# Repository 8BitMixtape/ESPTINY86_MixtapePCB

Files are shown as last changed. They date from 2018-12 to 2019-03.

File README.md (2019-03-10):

# ESPTINY86_MixtapePCB

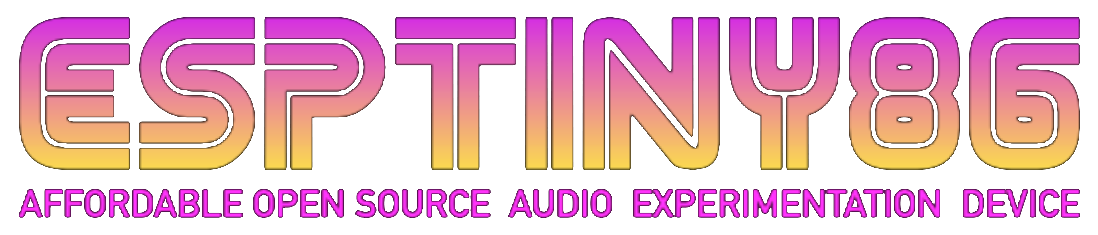
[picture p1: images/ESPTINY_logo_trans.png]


See more about the ESPTINY86 on https://github.com/esptiny86

# Where to get it

http://shop.8bitmixtape.cc/product/esptiny86-wifi-32bit-mixtape/

# Make Your Own 

## Preview of PCB gerber files

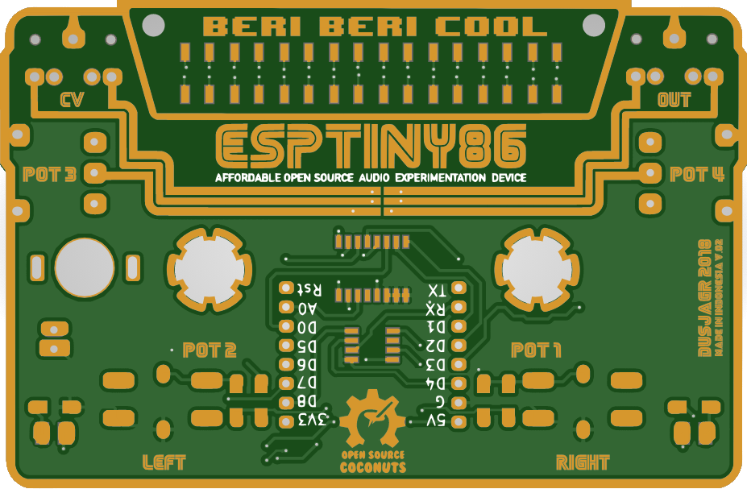
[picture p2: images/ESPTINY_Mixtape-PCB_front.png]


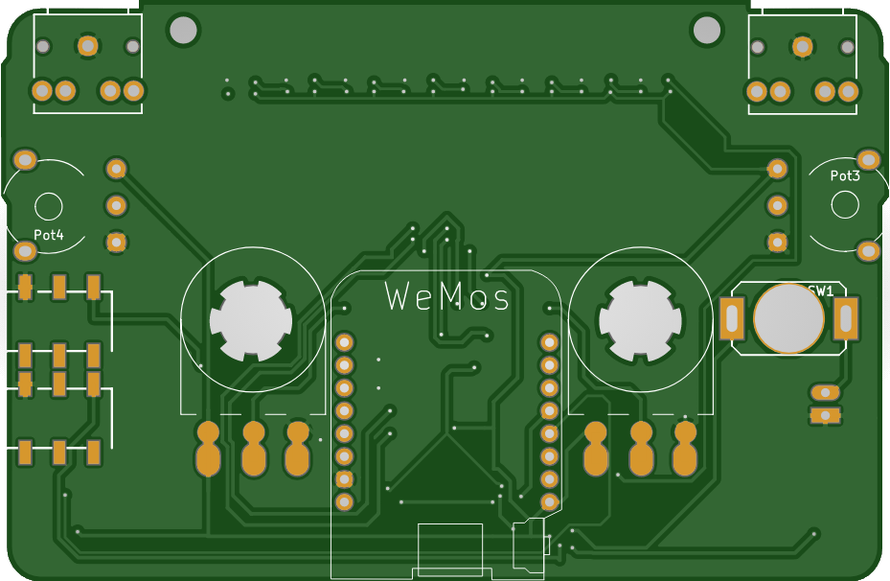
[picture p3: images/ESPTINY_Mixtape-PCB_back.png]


## How to solder it

Check the parts placement .pdf and warm up your soldering iron

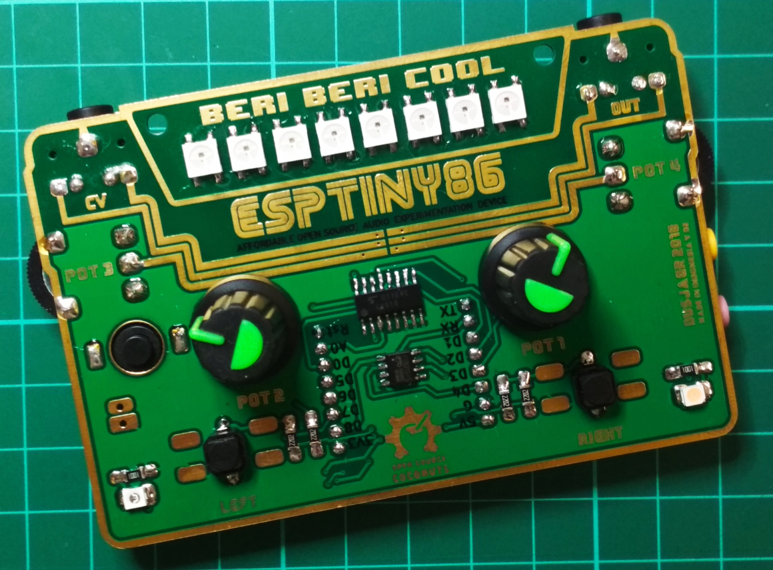
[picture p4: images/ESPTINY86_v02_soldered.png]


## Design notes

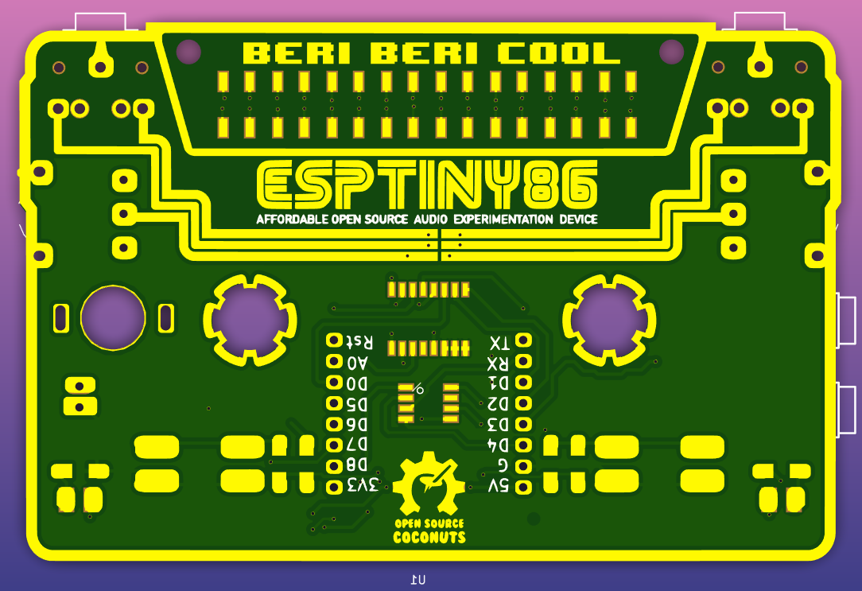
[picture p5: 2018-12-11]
images/ESPTINY86_3d_view_front_flat.png

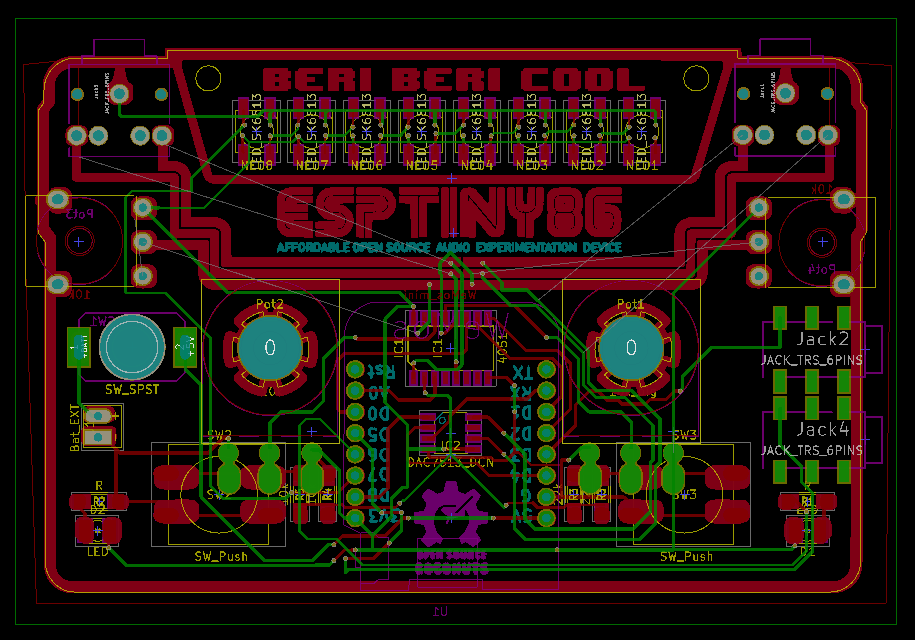
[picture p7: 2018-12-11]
images/ESPTINY86_KiCAD.png

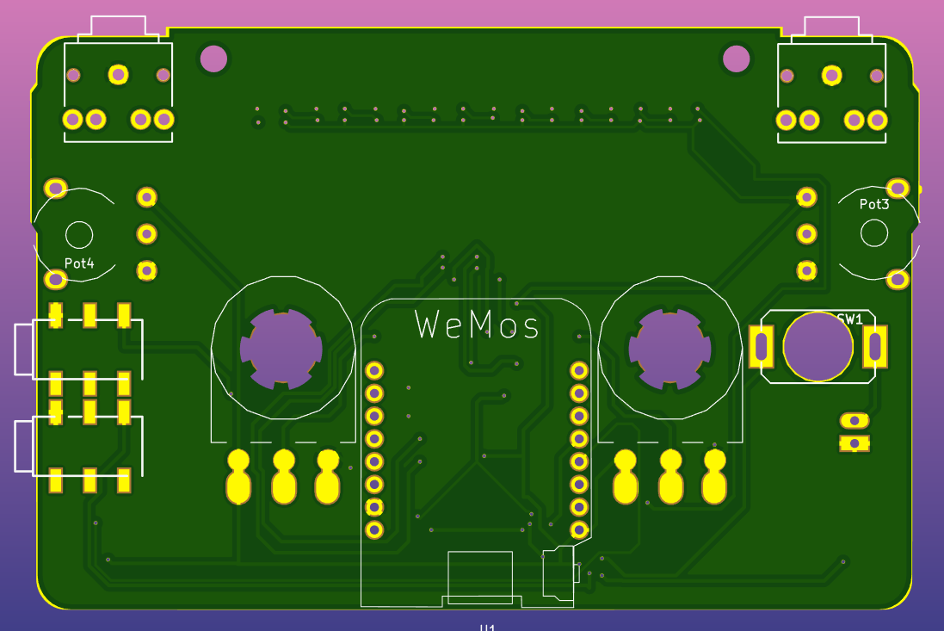
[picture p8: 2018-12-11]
images/ESPTINY86_3d_view_back_flat.png

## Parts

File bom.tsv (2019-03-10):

References | Qty | Description | Part Number | Manufacturer | Mouser | Digikey | Other Supplier
R1 | 1 | 22K 1206 | RC1206FR-0722KL | Yageo | 603-RC1206FR-0722KL | 311-22.0KFRCT-ND
R2 | 1 | 22K 1206 | RC1206FR-0722KL | Yageo | 603-RC1206FR-0722KL | 311-22.0KFRCT-ND
R3 | 1 | 22K 1206 | RC1206FR-0722KL | Yageo | 603-RC1206FR-0722KL | 311-22.0KFRCT-ND
R4 | 1 | 22K 1206 | RC1206FR-0722KL | Yageo | 603-RC1206FR-0722KL | 311-22.0KFRCT-ND
R5 | 1 | 1K 1206 | RC1206FR-071KL | Yageo | 603-RC1206FR-071KL | 311-1.00KFRCT-ND
R6 | 2 | 1K 1206 | RC1206FR-071KL | Yageo | 603-RC1206FR-071KL | 311-1.00KFRCT-ND
IC1 | 1 | CMOS 4051
IC2 | 1 | PT8211
D1 mini Pro | 1 | D1 mini Pro ESP8266 dev board
LED Power (red) | 1 | TOP-led (3528 package) | AA3528SURSK | Kingbright | 604-AA3528SURSK | 754-1537-1-ND
LED Signal (blue) | 1 | TOP-led (3528 package) | AA3528QBS/D | Kingbright | 604-AA3528QBS/D
Pot | 2 | 10k lin Potentiometer, 16mm (6mm shaft dia, 15mm shaft length) | P160KN-0QC15B10K | BI Technologies / TT Electronics | 858-P160KN-0QC15B10K
Pot-Wheel | 2 | 10k lin Wheel Potentiometer
Better to source on ali / taobao
NEO pixel | 1 | NEO pixel 10-pack (SK6812) | 1655 | Adafruit | 485-1655
Jack1 | 2 | Mini-Jack female 3.5mm | SJ1-3525NG | CUI | 490-SJ1-3525NG |  | https://www.aliexpress.com/item/1000pcs-Phone-Jack-3-5mm-5-pin-stereo-audio-socket-for-3-poles-earphone-plug-through/32664057697.html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
But1 | 2 | Tactile Switches | 1571621-1 | TE Connectivity / Alcoswitch | 506-1571621-1
SW1 | 1 | Push Switch |  |  |  |  | https://www.aliexpress.com/item/Free-shipping-200pcs-DC-30V-1A-Black-On-Off-Mini-Push-Button-Switch-for-Electric-Torch/32567227670.html
Jack3 | 2 | Mini-Jack female 3.5mm
Knob | 2 | from Taide |  |  |  |  | http://www.taydaelectronics.com/catalogsearch/result/?q=Black+Plastic+Knob+with

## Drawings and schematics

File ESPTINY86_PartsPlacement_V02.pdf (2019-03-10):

# Parts Placement - Complete

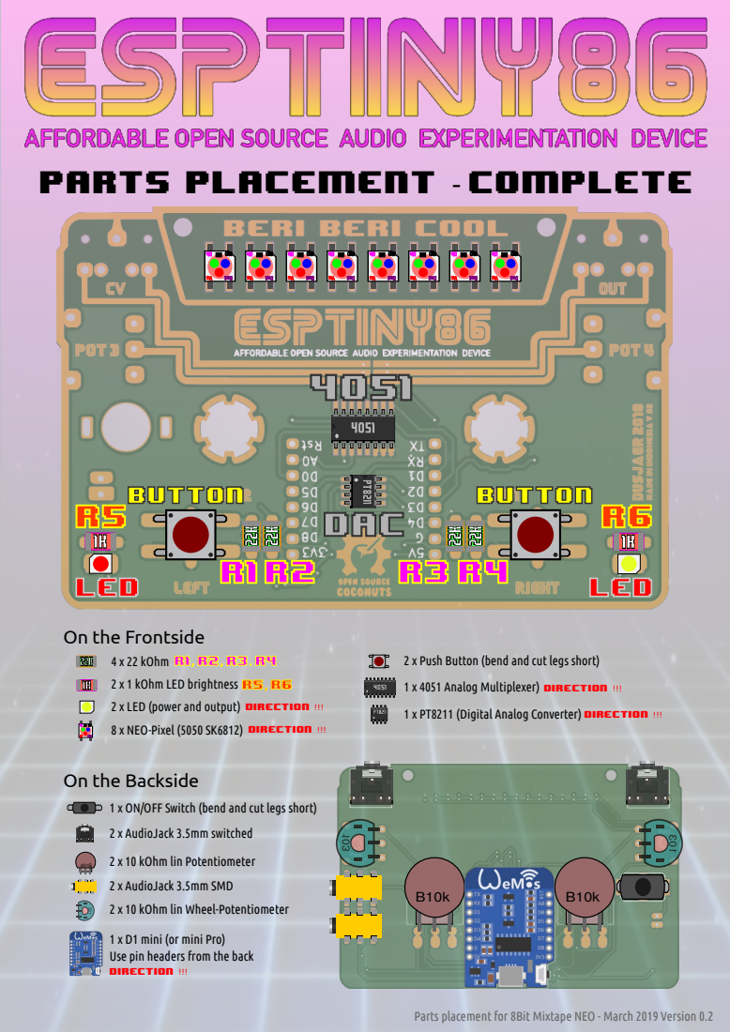
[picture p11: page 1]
LED; DAC; Button; direction !!!

On the Frontside

4 x 22 kOhm
2 x 1 kOhm LED brightness
2 x LED (power and output)
8 x NEO-Pixel (5050 SK6812)

2 x Push Button (bend and cut legs short)
1 x 4051 Analog Multiplexer)
1 x PT8211 (Digital Analog Converter)

On the Backside

1 x ON/OFF Switch (bend and cut legs short)
2 x AudioJack 3.5mm switched

2 x 10 kOhm lin Potentiometer
2 x AudioJack 3.5mm SMD
2 x 10 kOhm lin Wheel-Potentiometer

1 x D1 mini (or mini Pro)
Use pin headers from the back

Parts placement for 8Bit Mixtape NEO - March 2019 Version 0.2

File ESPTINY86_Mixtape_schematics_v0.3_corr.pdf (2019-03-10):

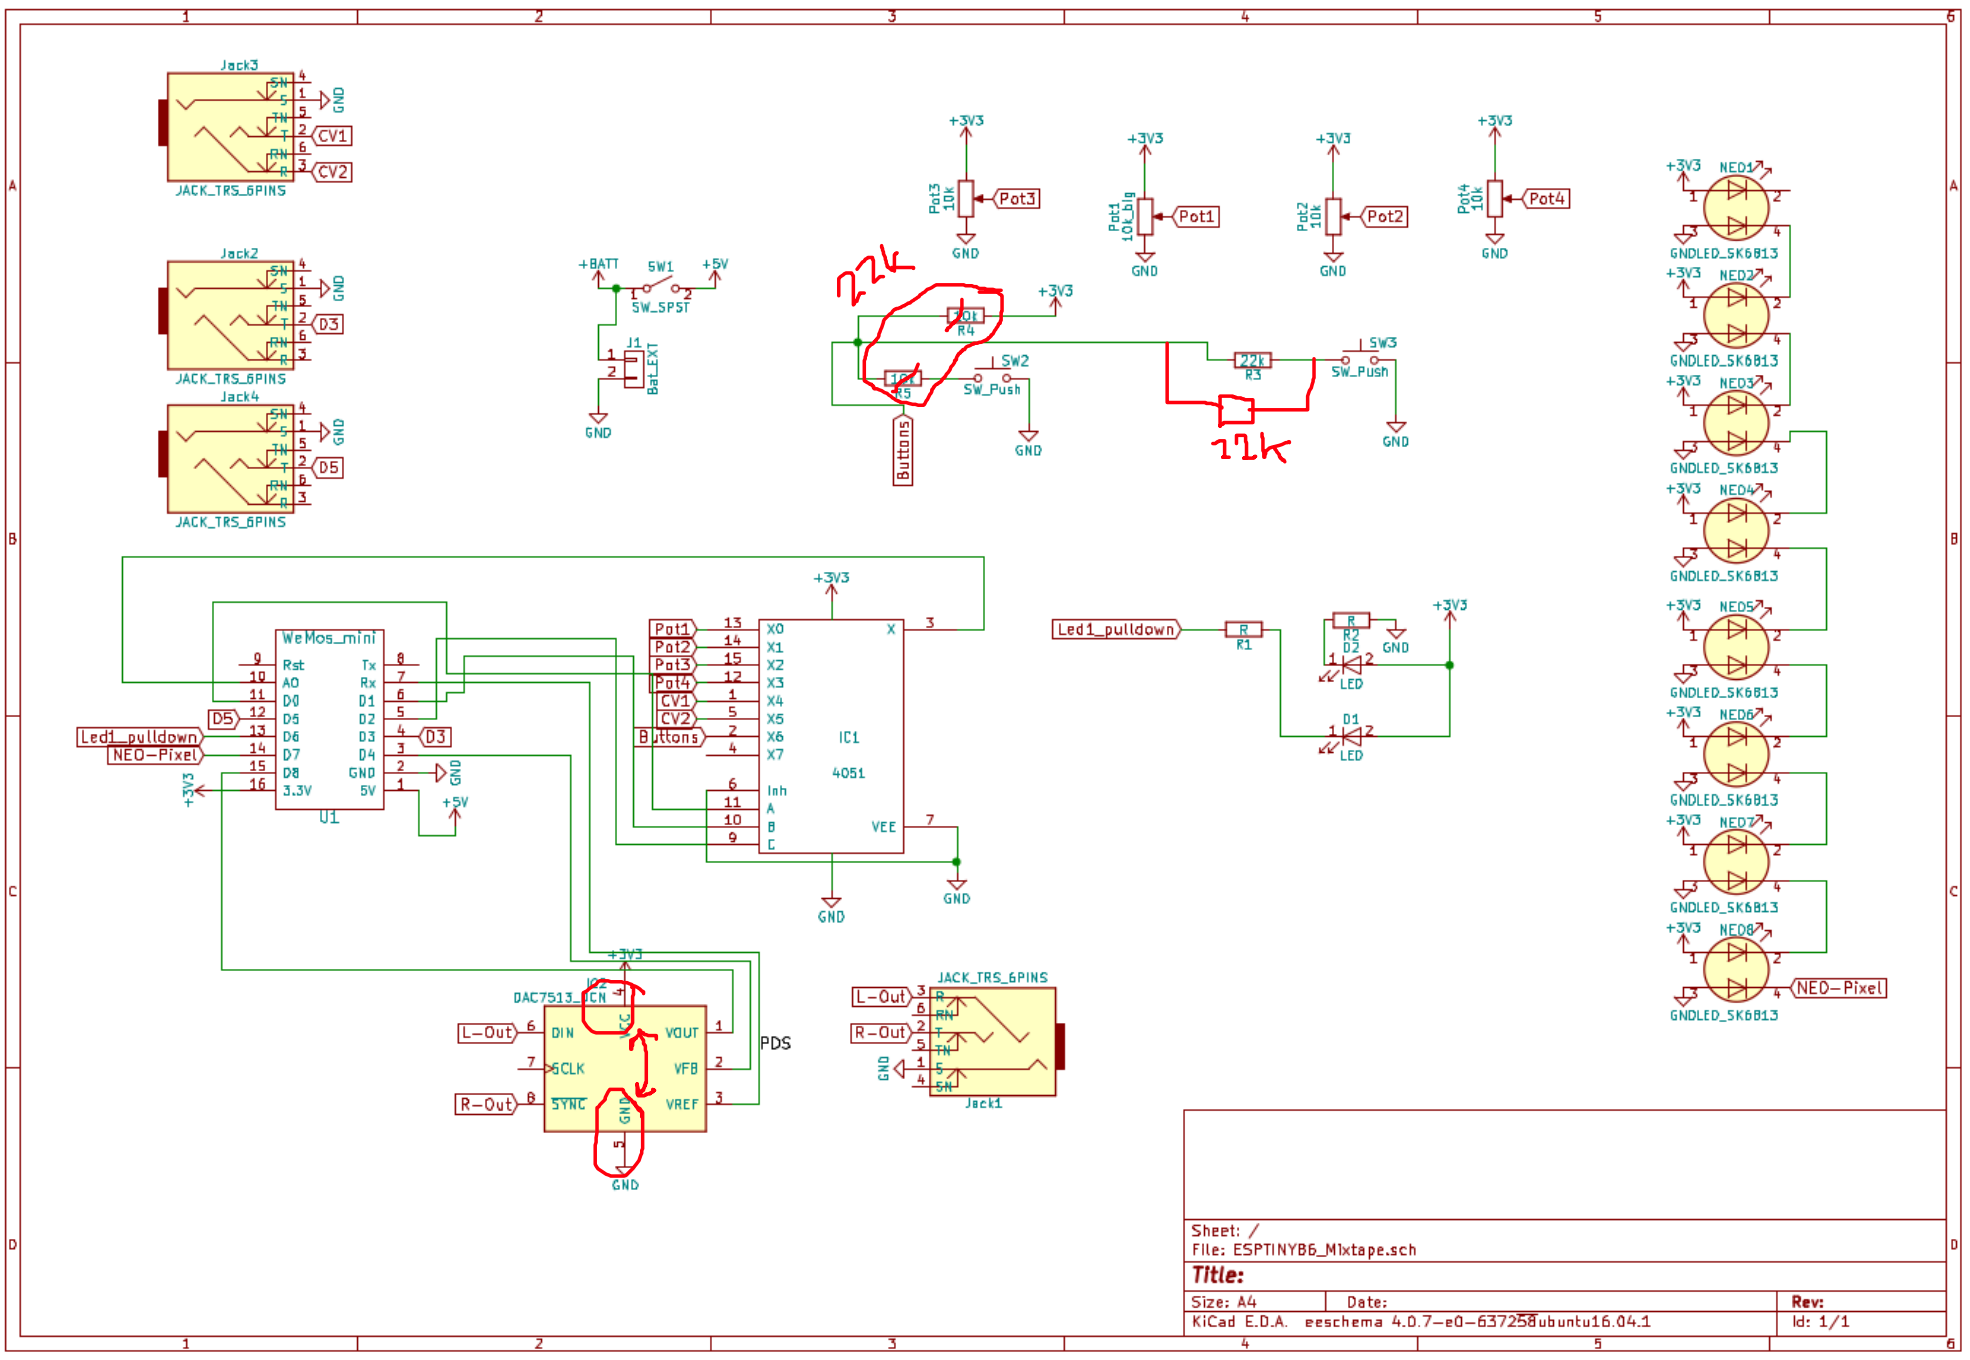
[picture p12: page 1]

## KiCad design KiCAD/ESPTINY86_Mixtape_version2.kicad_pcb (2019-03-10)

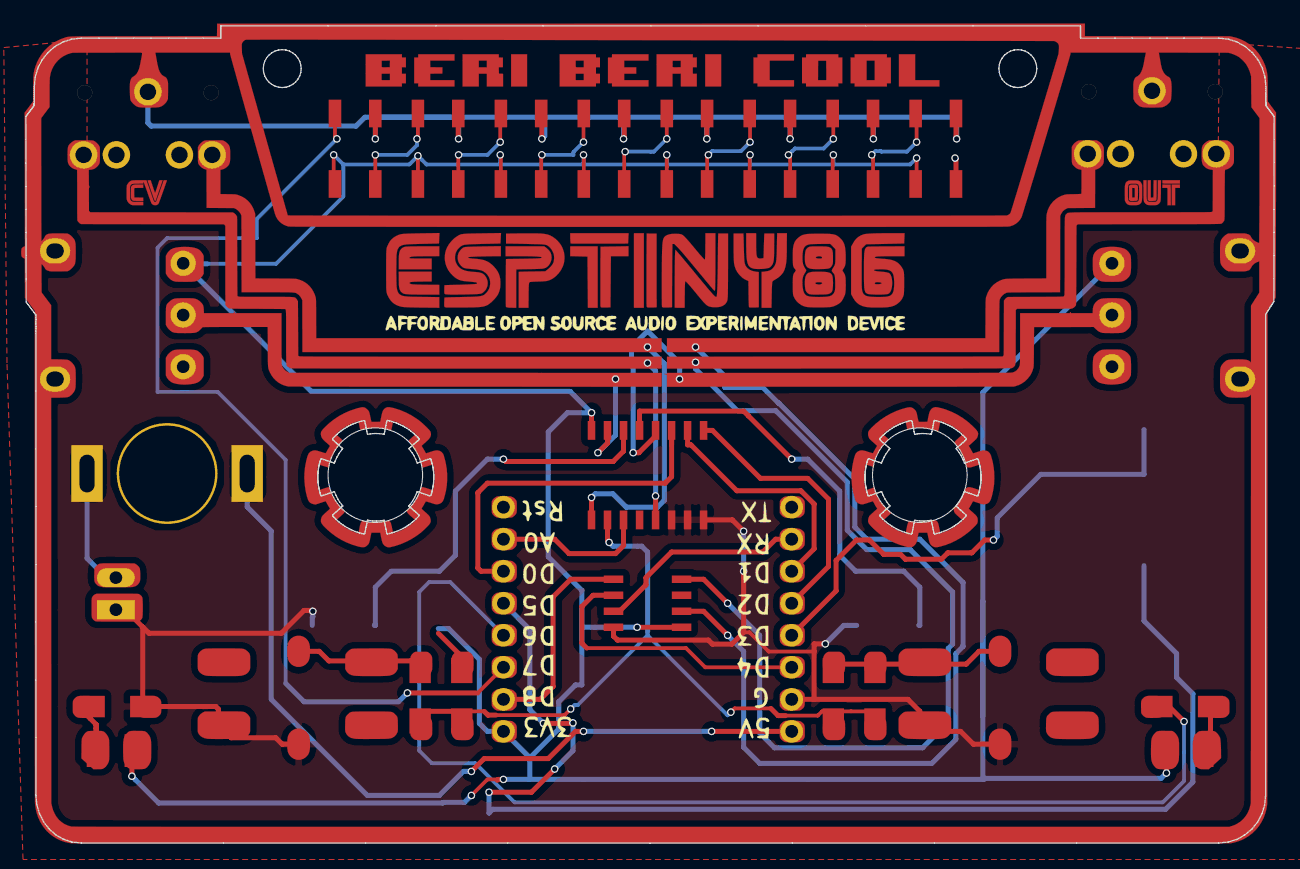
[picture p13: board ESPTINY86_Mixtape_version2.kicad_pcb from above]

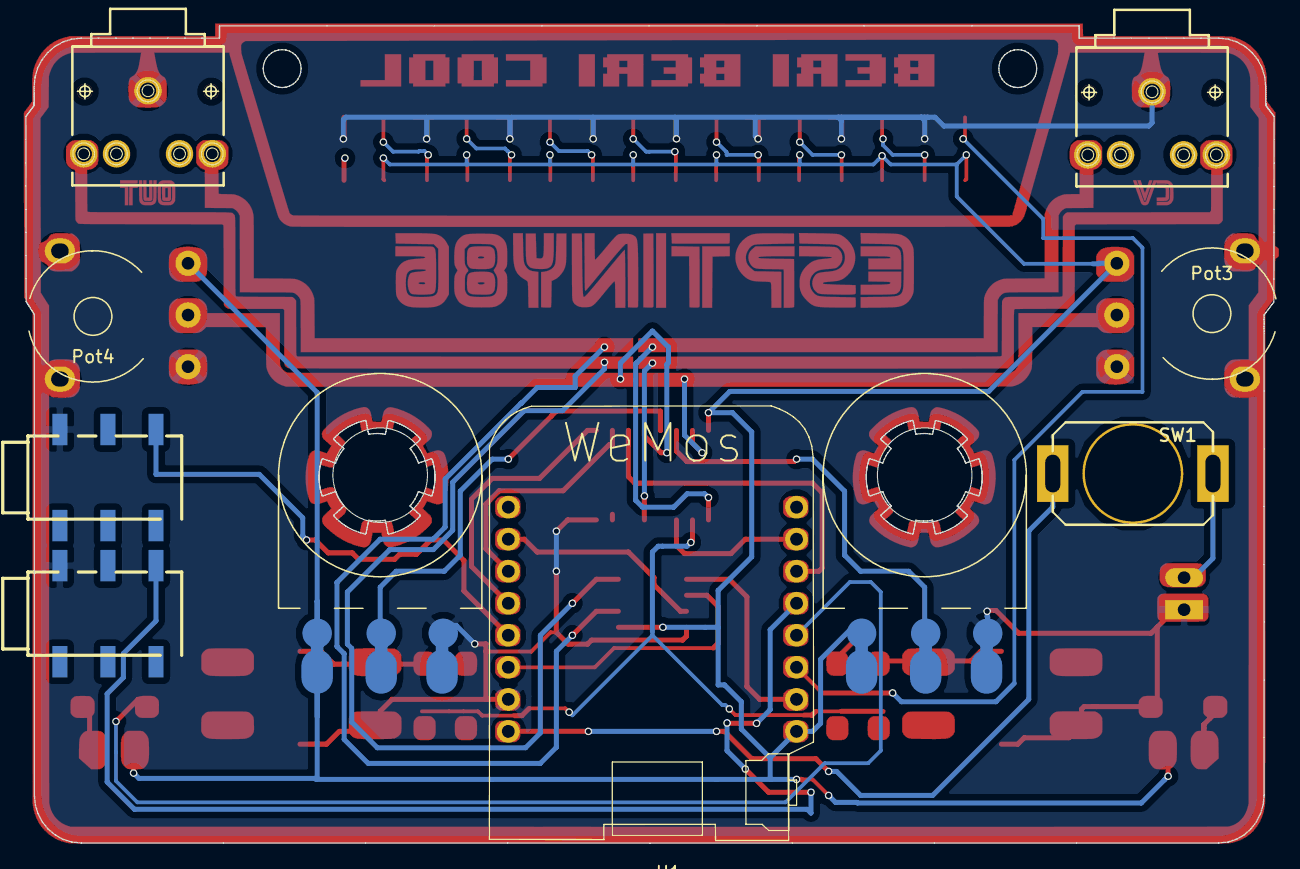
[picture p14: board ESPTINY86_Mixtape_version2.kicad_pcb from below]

Board: 2 copper layers, 99.0 x 64.8 mm, 32 parts (8 on the bottom side), 35 nets.

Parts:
Coconut: LOGO; Coconut_Logo_small_Mask
D1, D2: LED; TopLED_2835
IC1: 4051; 4xxx_SOIC-16W_Pitch1.27mm
IC2: DAC7513_DCN; SOIC-8_3.9x4.9mm_Pitch1.27mm
J1: Bat_EXT; Bat_connector+-
Jack1, Jack3: JACK_TRS_6PINS; AUDIO-Jack_3.5mm_5Pin
Jack2, Jack4: JACK_TRS_6PINS; AUDIO-JACK-3.5mm_SMD_noHole
NEO1, NEO2, NEO3, NEO4, NEO5, NEO6, NEO7, NEO8: LED_SK6813; Mixtape_NEO_WS2812B
Pot1: 10k_big; Potentiometer_backPads_noHole
Pot2: 10k; Potentiometer_backPads_noHole
Pot3: 10k; Potentiometer_wheel_inv
Pot4: 10k; Potentiometer_wheel
R1, R2: R; R_1206_Mixtape
R3, R3#2: 22k; R_1206_Mixtape
R4, R5: 10k; R_1206_Mixtape
SW1: SW_SPST; Push_SWITCH_hole
SW2, SW3: SW_Push; SW_PUSH-8mm_SMD
U1: WeMos_mini; WeMOS_ESP

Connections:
+3V3: D1.2, D2.2, IC1.16, IC2.5, NEO1.1, NEO2.1, NEO3.1, NEO4.1, NEO5.1, NEO6.1, NEO7.1, NEO8.1, Pot1.1, Pot2.1, Pot3.1, Pot4.1, R4.1, U1.16
+5V: SW1.2, U1.1
+BATT: J1.1, SW1.1
Buttons: IC1.2, R3.2, R3#2.2, R4.2, R5.2
CV1: IC1.1, Jack3.2
CV2: IC1.5, Jack3.3
D3: Jack2.2, U1.4
D5: Jack4.2, U1.12
GND: IC1.6, IC1.7, IC1.8, IC2.4, J1.2, Jack1.1, Jack2.1, Jack3.1, Jack4.1, NEO1.3, NEO2.3, NEO3.3, NEO4.3, NEO5.3, NEO6.3, NEO7.3, NEO8.3, Pot1.3, Pot2.3, Pot3.3, Pot4.3, R2.1, SW2.2, SW3.2, U1.2
L-Out: IC2.6, Jack1.3
Led1_pulldown: R1.2, U1.13
NEO-Pixel: NEO8.4, U1.14
unnamed: D1.1, R1.1
unnamed: D2.1, R2.2
unnamed: IC1.3, U1.10
unnamed: IC1.9, U1.5
unnamed: IC1.10, U1.6
unnamed: IC1.11, U1.11
unnamed: IC2.1, U1.15
unnamed: IC2.3, U1.7
unnamed: NEO1.4, NEO2.2
unnamed: NEO2.4, NEO3.2
unnamed: NEO3.4, NEO4.2
unnamed: NEO4.4, NEO5.2
unnamed: NEO5.4, NEO6.2
unnamed: NEO6.4, NEO7.2
unnamed: NEO7.4, NEO8.2
unnamed: R3.1, R3#2.1, SW3.1
unnamed: R5.1, SW2.1
Pot1: IC1.13, Pot1.2
Pot2: IC1.14, Pot2.2
Pot3: IC1.15, Pot3.2
Pot4: IC1.12, Pot4.2
R-Out: IC2.8, Jack1.2
problem: IC2.2, U1.3

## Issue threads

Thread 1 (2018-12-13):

error - unable to export please fix and try again

5shekel, 2018-12-13:
i'm documenting here an issue i have
be kicad
pcbnow>file>export>speccetra dsn

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

the error refers to a dup
`multiple symbols have identical reference IDs of "R3"`

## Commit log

2018-12-11 Fixed~ Board KiCAD
    [ESPTINY86_Mixtape_version2.kicad_pcb, ESPTINY86_Mixtape_version2.sch, d1_mini_shield.kicad_pcb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]
2018-12-13 fixing the schematic
    [ESPTINY86_Mixtape_version2.sch]
2019-03-10 adding parts s placement
    [ESPTINY86_Mixtape_version2-B.Cu.gbr, ESPTINY86_Mixtape_version2-B.Mask.gbr, ESPTINY86_Mixtape_version2-B.SilkS.gbr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]
2019-03-10 schematics corrected
2019-03-10 adding fake BOM
    [bom.tsv]
2019-03-10 fixing BOM
    [bom.tsv]
